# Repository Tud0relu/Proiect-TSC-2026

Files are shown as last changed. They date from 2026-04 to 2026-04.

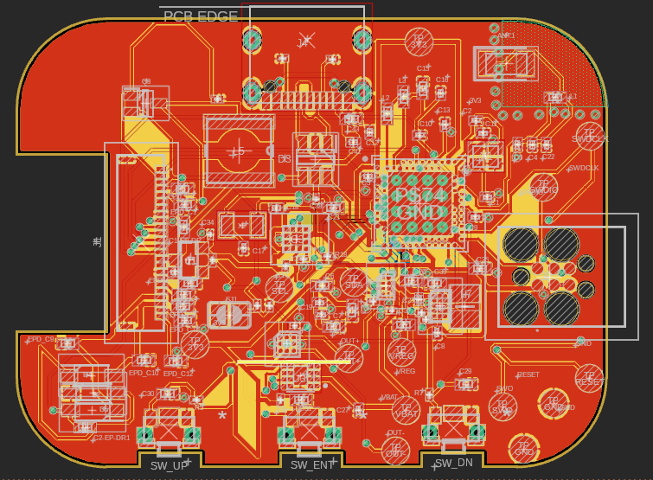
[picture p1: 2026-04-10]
Images/PCB.png

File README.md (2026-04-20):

# InkTime — E-Ink Smartwatch Hardware Documentation

> **InkTime** is a custom smartwatch built around the **Nordic nRF52840** SoC featuring an e-paper (EPD) display, haptic feedback, 3-axis accelerometer, smart battery management, and USB-C charging — all packed into a compact wearable PCB.

---

## Table of Contents

1. [Block Diagram](#block-diagram)
2. [Bill of Materials (BOM)](#bill-of-materials-bom)
3. [Hardware Functionality Description](#hardware-functionality-description)
   - [Microcontroller — Nordic nRF52840](#microcontroller--nordic-nrf52840)
   - [Power Architecture](#power-architecture)
   - [E-Paper Display Interface](#e-paper-display-interface)
   - [IMU — Bosch BMA423](#imu--bosch-bma423)
   - [Haptic Driver — TI DRV2605](#haptic-driver--ti-drv2605)
   - [Fuel Gauge — MAX17048](#fuel-gauge--max17048)
   - [RF & Antenna](#rf--antenna)
   - [User Interface — Buttons](#user-interface--buttons)
   - [USB-C Connectivity](#usb-c-connectivity)
   - [Debug Interface](#debug-interface)
4. [nRF52840 Pin Assignment](#nrf52840-pin-assignment)
5. [Power Consumption Estimates](#power-consumption-estimates)
6. [PCB Design Notes](#pcb-design-notes)
7. [Enclosure](#enclosure)

---

## Block Diagram

```
                        ┌─────────────────────────────────────────────────────┐
                        │                  InkTime PCB                        │
                        │                                                     │
  USB-C (J4)            │  ┌───────────┐     I²C (SDA/SCL)   ┌───────────┐  │
 ──────────────► VBUS ──┼─►│ BQ25180   │◄───────────────────►│ BMA423    │  │
  KH-TYPE-C-16P         │  │ (Charger) │◄──P0.11 INT         │ (IMU)     │  │
                        │  │  IC1      │                      │  IC3      │  │
                        │  └─────┬─────┘  I²C (SDA/SCL)  ┌──┴─────────┐ │  │
                        │        │ SYS ──────────────────►│ DRV2605    │ │  │
  LiPo Battery          │        │           P0.12 EN     │ (Haptic)   │ │  │
 ──────────────► VBAT ──┼────────┤           OUT+/OUT─►  │   IC2      │ │  │
                        │        ▼                       └────────────┘ │  │
                        │  ┌───────────┐                  ┌────────────┐ │  │
                        │  │ RT6160    │  3V3 Rail        │ MAX17048   │ │  │
                        │  │ Buck-Boost│──────────────────► (FuelGauge)│ │  │
                        │  │  IC9      │                  │   U3       │ │  │
                        │  └───────────┘                  └────────────┘ │  │
                        │        │                              I²C ──────┘  │
                        │        │ 3V3                                        │
                        │        ▼                                            │
                        │  ┌─────────────────────────────────────────────┐   │
                        │  │         Nordic nRF52840  (U1)               │   │
                        │  │  BT5.0 + 802.15.4 + ARM Cortex-M4F 64MHz   │   │
                        │  │                                             │   │
                        │  │  SPI ──────────────────────► EPD Display   │   │
                        │  │  I²C ──────────────────────► BMA423 / DRV  │   │
                        │  │  I²C ──────────────────────► MAX17048 / DRV│   │
                        │  │  GPIO ─────────────────────► EPD DC/RST/CS │   │
                        │  │  GPIO ─────────────────────► HAPTIC EN     │   │
                        │  │  GPIO ─────────────────────► Buttons x3    │   │
                        │  │  SWDIO/SWDCLK ─────────────► TC2030 J2     │   │
                        │  │  ANT ──────────────────────► 2450AT18B100E │   │
                        │  └─────────────────────────────────────────────┘   │
                        │                                                     │
                        │  EPD Power Rail (3V3_EPD)  Q1(P-MOSFET) + Q3(N-MOSFET) │
                        │  FPC Connector J1 ──────────────────────► E-Paper Display│
                        └─────────────────────────────────────────────────────┘
```

> **Key interfaces:** SPI (EPD display), I²C (BMA423 + DRV2605 + MAX17048 + BQ25180), USB-C (charging + USB 2.0 FS), SWD (debug/programming).

---

## Bill of Materials (BOM)

| # | Qty | Designator | Component | Value / MPN | Package | JLCPCB / LCSC | Datasheet |
|---|-----|---|---|---|---|---|---|
| 1 | 1 | U1 | Nordic nRF52840 | NRF52840_QF | AQFN-73 7×7mm | — | [Datasheet](https://infocenter.nordicsemi.com/pdf/nRF52840_PS_v1.7.pdf) |
| 2 | 1 | IC1 | Li-Ion charger | BQ25180YBGR | 8-DSBGA 1.6×1.1mm | [C2678081](https://jlcpcb.com/partdetail/TexasInstruments-BQ25180YBGR/C2678081) | [Datasheet](https://www.ti.com/lit/ds/symlink/bq25180.pdf) |
| 3 | 1 | IC2 | Haptic driver ERM/LRA | DRV2605YZFR | 9-BGA 1.44×1.44mm | [C2903721](https://jlcpcb.com/partdetail/TexasInstruments-DRV2605YZFR/C2903721) | [Datasheet](https://www.ti.com/lit/ds/symlink/drv2605.pdf) |
| 4 | 1 | IC3 | Accelerometer | BMA423 | LGA-12 2×2mm | [C332461](https://jlcpcb.com/partdetail/BoschSensortec-BMA423/C332461) | [Datasheet](https://www.bosch-sensortec.com/media/boschsensortec/downloads/datasheets/bst-bma423-ds000.pdf) |
| 5 | 1 | IC9 | Buck-boost DC/DC | RT6160AWSC | WCSP-15 1.4×2.3mm | [C2844520](https://jlcpcb.com/partdetail/Richtek-RT6160AWSC/C2844520) | [Datasheet](https://www.richtek.com/assets/product_file/RT6160A/DS6160A-00.pdf) |
| 6 | 1 | U3 | 1-cell fuel gauge | MAX17048G+T10 | TDFN-8 2×2mm | — | [Datasheet](https://datasheets.maximintegrated.com/en/ds/MAX17048-MAX17049.pdf) |
| 7 | 1 | ANT1 | 2.45 GHz chip antenna | 2450AT18B100E | 3.2×1.6×1.4mm SMD | [C404959](https://jlcpcb.com/partdetail/JohansonDielectrics-2450AT18B100E/C404959) | [Datasheet](https://www.johansontechnology.com/datasheets/2450AT18B100E.pdf) |
| 8 | 1 | J1 | FPC connector 24-pin | 503480-2400 | FPC 0.5mm RA SMD | [C311220](https://jlcpcb.com/partdetail/Molex-503480_2400/C311220) | [Datasheet](https://www.molex.com/pdm_docs/sd/5034802400_sd.pdf) |
| 9 | 1 | J4 | USB Type-C 16-pin | KH-TYPE-C-16P | SMD receptacle | — | [Datasheet](https://www.kinghelm.net/product/kh-type-c-16p.html) |
| 10 | 1 | J2 | SWD debug header | TC2030-IDC | Tag-Connect | — | [Datasheet](https://www.tag-connect.com/wp-content/uploads/bsk-pdf-manager/TC2030-IDC_1.pdf) |
| 11 | 1 | Q1 | P-MOSFET EPD power switch | DMG2305UX-7 | SOT-23 | — | [Datasheet](https://www.diodes.com/assets/Datasheets/DMG2305UX.pdf) |
| 12 | 1 | Q3 | N-MOSFET EPD gate driver | SI1308EDL-T1-GE3 | SC-70 | [C240327](https://jlcpcb.com/partdetail/VishayS-SI1308EDL_T1_GE3/C240327) | [Datasheet](https://www.vishay.com/docs/63399/si1308edl.pdf) |
| 13 | 3 | D2, D4, D5 | Schottky diode 30V/0.5A | MBR0530 | SOD-123 | [C191023](https://jlcpcb.com/partdetail/OnSemiconductor-MBR0530/C191023) | [Datasheet](https://www.onsemi.com/pdf/datasheet/mbr0530-d.pdf) |
| 14 | 1 | D3 | USB 2.0 ESD protection | USBLC6-2SC6Y | SOT-363 | [C145414](https://jlcpcb.com/partdetail/STMicroelectronics-USBLC6_2SC6Y/C145414) | [Datasheet](https://www.st.com/resource/en/datasheet/usblc6-2.pdf) |
| 15 | 1 | L5 | Power inductor 68uH | Würth 744043680 | IND 4.8×2.8mm | [C516667](https://jlcpcb.com/partdetail/WurthElektronik-744043680/C516667) | [Datasheet](https://www.we-online.com/catalog/datasheet/744043680.pdf) |
| 16 | 1 | L7 | Power inductor 0.47uH | FTC252012SR47MBCA | L1608 2×1.6mm | [C5832368](https://jlcpcb.com/partdetail/6763488-FTC252012SR47MBCA/C5832368) | [Datasheet](https://product.tdk.com/info/en/documents/catalog/clq_prog_en_ds_1.pdf) |
| 17 | 1 | X1 | Crystal 32 MHz | 32MHz SMD | Crystal_2016 | — | Nordic reference crystal |
| 18 | 1 | X2 | Crystal 32.768 kHz | 32.768kHz | Crystal_3215 | — | Nordic reference crystal |
| 19 | 3 | SW_UP, SW_DN, SW_ENT | Tactile switch | EVP-AKE31A | SMD | [C2689689](https://jlcpcb.com/partdetail/Panasonic-EVP_AKE31A/C2689689) | [Datasheet](https://industrial.panasonic.com/ww/products/pt/tactile-switches/models/EVP-AKE31A) |
| 20 | 1 | L1 | RF inductor 3.9nH | 3.9nH | 0402 | — | Matching network |
| 21 | 1 | L2 | RF choke 10uH | 10uH | 0402 | — | DC feed |
| 22 | 1 | L3 | RF filter | 15nH | 0402 | — | Matching network |
| 23 | 4 | C14, C20, C21, C6 | MLCC capacitor 4.7uF | 4.7uF | 0402 | — | Decoupling |
| 24 | 7 | C10, C12, C13, C19, C5, C7, C8 | MLCC capacitor 100nF | 100nF | 0201 | — | Decoupling |
| 25 | 3 | C29, C30, C31 | MLCC capacitor 1uF | 1uF | 0402 | — | Button debounce |
| 26 | 3 | C1-EP-DR, C24, C39 | MLCC capacitor 10uF | 10uF | 0402 | — | Bulk decoupling |
| 27 | 9 | EPD_C1..C12 | MLCC capacitor 1uF/50V | 1uF/50V | 0402 | — | EPD power |
| 28 | 2 | R17, R18 | Resistor 3.3kΩ | 3K3 | 0201 | — | I²C pull-up |
| 29 | 2 | R1_USB, R2_USB | Resistor 5.1kΩ | 5K1 | 0201 | — | USB-C CC detection |
| 30 | 3 | R2, R3, R4 | Resistor 7.68kΩ | 7.68k | 0201 | — | Config resistors |
| 31 | 3 | R5, R7, R8 | Resistor 10kΩ | 10k | 0201 | — | Button pull-up |
| 32 | 3 | R2_EP_DR, R9, R_PWR_EPD | Resistor 10kΩ | 10K | 0201 | — | EPD / PMIC bias |
| 33 | 1 | SJ1 | Solder jumper | — | Solder Jumper | — | Config bridge |
| 34 | 14 | TP1–TP6, TP_* | Test points | — | TP_20R | — | Debug/test |

---

## Hardware Functionality Description

### Microcontroller — Nordic nRF52840

The **nRF52840** (U1) is the heart of InkTime. It is a single-chip multiprotocol SoC combining:

- **ARM Cortex-M4F** core @ 64 MHz with FPU
- **1 MB Flash** + **256 KB RAM**
- **Bluetooth 5.0 LE** (1 Mbps/2 Mbps/500 kbps/125 kbps) + IEEE 802.15.4 (Zigbee/Thread)
- **USB 2.0 Full-Speed** device controller (12 Mbps)
- Hardware AES-128 encryption, ARM TrustZone CryptoCell-310
- 48 GPIO pins, 3× TWI (I²C), 4× SPI, 2× UART, 12-bit ADC

The nRF52840 uses the internal DC/DC converter for lower power consumption. Supply is 3.3 V from IC9. Two crystals are used:
- **X1** — 32 MHz (RF clock, high-frequency crystal)
- **X2** — 32.768 kHz (LFCLK for RTC, sleep timekeeping)

The built-in USB 2.0 controller connects directly to the KH-TYPE-C-16P receptacle (J4) via the ESD-protected D+/D− lines, enabling USB DFU firmware updates without a dedicated USB-UART chip.

---

### Power Architecture

```
USB-C (VBUS 5V)
      │
      ▼
  BQ25180YBGR (IC1) ◄── LiPo battery (VBAT)
  Linear charger, up to 1A charge current
      │
      ▼ SYS rail (≈ VBAT or 4.2V when charging)
      │
      ▼
  RT6160AWSC (IC9)
  I²C-programmable buck-boost converter
  Input: 2.5V – 5.5V  |  Output: 3.3V @ up to 800mA
      │
      ▼ 3V3 rail (powers nRF52840, BMA423, DRV2605, MAX17048)
```

**BQ25180YBGR (IC1) — Li-Ion Battery Charger:**
- Input voltage: 3.8V–5.5V (VBUS from USB-C)
- Charge current: configurable via I²C (default ~200 mA, up to 1A)
- Integrated power path management: device runs from VBUS while simultaneously charging
- Interrupt line (!INT) → P0.11: alerts the MCU to status changes (charge complete, fault, OVP)
- I²C address: 0x6B on shared SDA/SCL bus (P0.06/P0.07)

**RT6160AWSC (IC9) — Buck-Boost Regulator:**
- Input: SYS rail (2.6V–5.5V)
- Output: fixed 3.3V ±2% at up to 800mA
- Operates in both step-up (battery near discharge) and step-down (charging) modes
- Enables reliable 3.3V operation down to VBAT ≈ 2.5V, extending battery life
- Enable controlled by VREG signal (always-on in normal operation)
- L7 (0.47uH) is the switching inductor; C25, C33 (22uF) are output caps

**MAX17048G+T10 (U3) — Battery Fuel Gauge:**
- ModelGauge algorithm: estimates State of Charge (SoC %) without coulomb counting
- I²C address: 0x36 on shared I²C bus
- ALERT pin → P0.10 (NFC2): configurable SoC threshold interrupt (e.g., alert at <5%)
- Powered from VBAT directly for always-on monitoring
- Current consumption: 3µA typical in active, 0.5µA in hibernate

---

### E-Paper Display Interface

The watch uses an e-paper (EPD) display connected via **Molex 503480-2400 FPC connector (J1)** — a 24-pin, 0.5mm pitch ZIF socket. The nRF52840 drives the EPD over **SPI** with additional GPIO control lines:

| Signal | nRF52840 Pin | Direction | Function |
|---|---|---|---|
| SCK | P0.02 | OUT | SPI clock |
| MOSI | P0.03 | OUT | SPI data |
| EPD_CS | P0.05 | OUT | Chip select (active low) |
| EPD_DC | P0.15 | OUT | Data/Command select |
| EPD_RST | P0.16 | OUT | Hardware reset (active low) |
| EPD_BUSY | P0.17 | IN | Busy signal from display controller |

**EPD Power Supply:**
The e-paper panel requires a higher-voltage supply (typically 20–40V internally generated by its own controller IC), but its logic/interface side runs on 3.3V. A dedicated **3V3_EPD** rail is created by an additional path controlled by:
- **Q1 (DMG2305UX-7)** — P-channel MOSFET acting as a high-side power switch for the EPD 3.3V supply, controlled by `R_PWR_EPD`
- **Q3 (SI1308EDL)** — N-channel MOSFET for EPD gate driver control
- **D2, D4, D5 (MBR0530)** — Schottky diodes for EPD voltage rail protection and PREVGH/PREVGL rail generation (required by most EPD controllers like UC8176/SSD1680)

This architecture ensures the EPD power is only active when needed, saving power during sleep.

---

### IMU — Bosch BMA423

The **BMA423** (IC3) is a triaxial, low-g accelerometer designed for wearables:

- **Range:** ±2g / ±4g / ±8g / ±16g (configurable)
- **Resolution:** 12-bit
- **Interface:** I²C (address 0x18, CSB pin pulled to VDD → secondary address disabled)
- **Features:** Built-in step counter, wrist-wear wake-up, double-tap/single-tap detection, activity recognition
- **Power:** 170µA active, 2µA in suspend, ~0.9µA in deep suspend
- **Supply:** 1.71V–3.6V (VDDIO and VDD both connected to 3.3V rail)

**Connections:**
- SDA → P0.06 (shared I²C bus)
- SCL → P0.07 (shared I²C bus)
- INT1 → P0.08: wake-up interrupt (step counter, gesture)
- INT2 → P1.08: secondary interrupt (configurable)
- CSB → 3V3 (I²C mode selection)

The BMA423 enables the watch to detect wrist rotation (raise-to-wake), count steps, and recognize sleep/wake cycles without MCU involvement.

---

### Haptic Driver — TI DRV2605

The **DRV2605YZFR** (IC2) provides haptic feedback to a motor (ERM or LRA type):

- **Interface:** I²C (address 0x5A)
- **Built-in waveform library:** 123 pre-loaded haptic waveforms (ROM)
- **Smart Loop Architecture:** auto-resonance tracking for LRA motors
- **Overdrive/brake control** for precise tactile feel
- **Supply:** 2.7V–5.5V (connected to local 3.3V rail)
- **Output current:** ±1.2A peak

**Connections:**
- SDA → P0.06 (shared I²C bus)
- SCL → P0.07 (shared I²C bus)
- EN → P0.12: enable pin (active high, controls driver power state)
- OUT+ / OUT− → motor terminals (differential drive)
- REG output decoupled by C32 (1uF)

I²C address 0x5A is hardwired (ADDR pin tied to GND internally).

---

### RF & Antenna

The **2450AT18B100E** (ANT1) from Johanson Technology is a multilayer ceramic chip antenna tuned for 2.4–2.5 GHz:

- **Gain:** 0 dBi typical
- **Impedance:** 50Ω
- **Size:** 3.2×1.6×1.4mm

RF matching network (π-filter):
- **L1** (3.9nH) — series matching inductor from ANT pin of nRF52840
- **C3, C4** (1pF each) — shunt capacitors for impedance matching
- **L2** (10uH) + **DCC** node — DC feed inductor for the internal PA supply
- **C9** (820pF), **C11** (100pF), **C3/C4** (1pF) — harmonics filtering

The antenna is placed at the corner of the PCB, away from the battery, with a keep-out zone under the radiating element per Nordic reference design guidelines.

---

### User Interface — Buttons

Three tactile switches (**Panasonic EVP-AKE31A**) provide the user interface:

| Designator | Function | nRF52840 Pin | Pull-up | Debounce Cap |
|---|---|---|---|---|
| SW_UP | Scroll Up / Confirm | P0.13 | R5 (10kΩ) | C30 (1uF) |
| SW_ENT | Enter / Select | P0.14 | R8 (10kΩ) | C31 (1uF) |
| SW_DN | Scroll Down / Back | P1.02 | R7 (10kΩ) | C29 (1uF) |

All buttons are **active-low** — pressing connects the GPIO to GND through the switch. The pull-up resistors (10kΩ) are tied to the 3.3V rail. Hardware RC debouncing is achieved by the 1uF capacitors in parallel with the switches.

The nRF52840 GPIOTE module handles button interrupts with minimal power overhead.

---

### USB-C Connectivity

The **KH-TYPE-C-16P** (J4) is a 16-pin USB Type-C receptacle providing:

- **VBUS (5V)** → IC1 (BQ25180) for charging
- **D+ / D−** → nRF52840 P0.12/P0.13 equivalent USB data pins for USB 2.0 FS
- **CC1 / CC2** → R1_USB, R2_USB (5.1kΩ each to GND): configure the port as a UFP (power sink), telling the attached charger to provide 5V/standard current
- **USBLC6-2SC6Y (D3)** — bidirectional TVS diode array on D+/D− lines for IEC 61000-4-2 ESD protection (±8kV contact discharge)

The nRF52840's built-in USB Full-Speed device controller (12 Mbps) enables:
- USB DFU (Device Firmware Upgrade) — drag-and-drop firmware flashing
- USB CDC (virtual serial port) — debug logging
- USB HID — optional time sync interface

---

### Debug Interface

**Tag-Connect TC2030-IDC (J2)** is a 6-pin spring-loaded programming/debug connector with no PCB footprint pins, saving board space:

| Pin | Signal | Function |
|-----|---|---|
| 1 | 3V3 | Target power sense |
| 2 | SWDIO | Serial Wire Debug I/O |
| 3 | GND | Ground |
| 4 | SWDCLK | Serial Wire Debug Clock |
| 5 | GND | Ground |
| 6 | RESET | nRF52840 hardware reset |

Additional debug test points on PCB: `TP_SWDIO`, `TP_SWDCLK`, `TP_3V3`, `TP_VBAT`, `TP_VREG`, `TP_SDA`, `TP_SCL`, `TP_ON`, `TP_OP`, `TP_SWO` (Serial Wire Output for ITM tracing).

---

## nRF52840 Pin Assignment

| GPIO Pin | Net / Signal | Connected To | Function |
|---|---|---|---|
| P0.00 / XL1 | P0.00/XL1 | X2 pin 1, C17 | 32.768 kHz LFXO in |
| P0.01 / XL2 | P0.01/XL2 | X2 pin 2, C18 | 32.768 kHz LFXO out |
| P0.02 / AIN0 | SCK | EPD FPC (J1 via schematic) | SPI clock for e-paper |
| P0.03 / AIN1 | MOSI | EPD FPC (J1) | SPI MOSI for e-paper |
| P0.05 / AIN3 | EPD_CS | EPD FPC (J1) | EPD chip select (active low) |
| P0.06 | SDA | IC1, IC3, IC2, U3, R2, R18 | I²C data (shared bus) |
| P0.07 | SCL | IC1, IC3, IC2, U3, R4, R17 | I²C clock (shared bus) |
| P0.08 | IMU_INT1 | IC3 (BMA423) INT1 | IMU interrupt 1 (step / wake) |
| P0.10 / NFC2 | ALERT | U3 (MAX17048) ALERT | Fuel gauge low-battery alert |
| P0.11 | PMIC_INT | IC1 (BQ25180) !INT | Charger status interrupt |
| P0.12 | HAPTIC_EN | IC2 (DRV2605) EN | Haptic driver enable |
| P0.13 | P0.13 | SW_UP, R5, C30 | Button UP (active low) |
| P0.14 | P0.14 | SW_ENT, R8, C31 | Button ENTER (active low) |
| P0.15 | EPD_DC | EPD FPC (J1) | EPD data/command select |
| P0.16 | EPD_RST | EPD FPC (J1) | EPD reset (active low) |
| P0.17 | EPD_BUSY | EPD FPC (J1) | EPD busy status input |
| P0.18 / RESET | RESET | J2 pin 6, TP_RESET | Hardware reset (active low) |
| P1.00 | SWO | TP_SWO | Serial Wire Output (ITM trace) |
| P1.02 | P1.02 | SW_DN, R7, C29 | Button DOWN (active low) |
| P1.08 | IMU_INT2 | IC3 (BMA423) INT2 | IMU interrupt 2 (configurable) |
| SWDIO | SWDIO | J2 pin 2, TP_SWDIO | SWD debug data |
| SWDCLK | SWDCLK | J2 pin 4, TP_SWDCLK | SWD debug clock |
| VBUS | VBUS | IC1 IN, C38, C21 | USB VBUS sense |
| D+ | D+ | J4, D3 | USB 2.0 FS D+ |
| D− | D− | J4, D3 | USB 2.0 FS D− |
| XC1/XC2 | N$3/N$4 | X1, C1, C2 | 32 MHz HFXO crystal |
| ANT | N$7 | L1, C3 | RF antenna feed |
| DCC | N$9 | L2 | PA DC feed |
| VDD (×4) | 3V3 | C6, C7, C8, C14 + IC9 VOUT | 3.3V supply |
| VDDH | 3V3 | IC9 VOUT | High-drive GPIO supply |
| VSS / VSS_PA / VSS_PAD | GND | Ground pour | Ground |

**I²C Bus Summary (P0.06 SDA / P0.07 SCL, 400 kHz Fast Mode):**

| Device | I²C Address | Pull-up |
|---|---|---|
| BQ25180 (IC1) | 0x6B | R2, R18 (3.3kΩ each) |
| BMA423 (IC3) | 0x18 | R2, R18 (3.3kΩ each) |
| DRV2605 (IC2) | 0x5A | R2, R18 (3.3kΩ each) |
| MAX17048 (U3) | 0x36 | R2, R18 (3.3kΩ each) |

All four devices share a single I²C bus with 3.3kΩ pull-up resistors (R17, R18 to 3V3). Effective pull-up for fast-mode at 400 kHz with 4 devices at ~100pF bus capacitance is within spec.

---

## Power Consumption Estimates

| State | Subsystem Active | Current Draw | Notes |
|---|---|---|---|
| **Deep sleep** | nRF52840 System OFF, RTC running | ~5–10 µA | 32.768kHz RTC, BMA wake-on-tilt |
| **BLE advertising** | nRF52840 BLE adv @ 1s interval | ~60–80 µA avg | Connectable undirected advertising |
| **BLE connected** | Connection interval 50ms | ~200–400 µA avg | — |
| **EPD update** | nRF52840 + EPD refresh 2s | ~15–25 mA peak | EPD full refresh draws spike current |
| **Haptic pulse** | DRV2605 + LRA 200ms | ~50–150 mA peak | Short pulses only |
| **Charging @ 200mA** | BQ25180 charging | 200 mA from VBUS | CC/CV profile |

**Estimated average daily consumption** (light wrist-watch use):
- 22h deep sleep (5µA) + 1h BLE connected (300µA) + 48 EPD updates/day (avg 0.5mA ×2s) ≈ **~0.4–0.6 mAh/day**

With a **100 mAh LiPo**, estimated battery life: **>6 months** with e-ink always-on display and minimal Bluetooth. With active BLE and hourly notifications, expect **4–8 weeks**.

---

## PCB Design Notes

- **Layer stack:** 2-layer PCB (Top + Bottom copper), 1.0mm FR4
- **Board dimensions:** ~45mm × 38mm (designed to fit circular wristwatch case)
- **Minimum trace width:** 0.1mm signal, 0.3mm power
- **Minimum clearance:** 0.1mm
- **Minimum drill:** 0.2mm (vias), 0.3mm annular ring
- **Surface finish:** HASL or ENIG (ENIG recommended for BGA/LGA pads)
- **Solder mask:** Green (standard), openings on all SMD pads
- **Component side:** All components on Top layer (single-sided SMT assembly possible)
- **Antenna keep-out:** 5mm clearance under 2450AT18B100E antenna element
- **Decoupling strategy:** 100nF 0201 caps placed within 0.5mm of each VDD pin, 4.7uF 0402 bulk caps placed per power domain

**Design Rules (JLCPCB 2-layer standard):**
- Min trace/space: 5/5 mil
- Min hole: 0.3mm
- Board outline tolerance: ±0.2mm
- Copper to board edge: ≥0.3mm

---

## Enclosure

The InkTime watch case is designed in **Autodesk Fusion 360** to fit the PCB precisely. Key features:

- **Outer dimensions:** 46mm × 38mm × 12mm (approximately)
- **Display window:** cutout for the EPD panel, with recessed bezel for protection
- **USB-C port cutout:** access to J4 on the bottom edge
- **Button apertures:** 3 side-mounted holes aligned with SW_UP, SW_ENT, SW_DN
- **Strap lugs:** 20mm standard watch band attachment points
- **PCB mounting:** 4× M1.4 screw bosses aligned with PCB corner keepout zones
- **Battery compartment:** cavity on back for 380mAh/100mAh flat LiPo cell
- **Material:** PLA/PETG for prototyping; Aluminum CNC or SLA resin for production

The 3D model is provided as `3DmodelFull.f3z` (Fusion 360 archive) and `3D.step` (neutral STEP format for other CAD tools).

---

## Repository Structure

```
Proiect-TSC-2026/
│
├── Hardware/
│   ├── PCB.brd
│   └── Schematic.sch
│
├── Images/
│   └── PCB.png
│
├── Manufactoring/
│   ├── PCB.cpl
│   ├── Schematic.bom.txt
│   └── gerber.zip
│
├── Mechanical/
│   ├── 3D.step
│   └── PCB_3D.f3d
│
├── LICENSE
└── README.md
```

---

*Project: InkTime Smartwatch | Hardware revision 6 | April 2026*

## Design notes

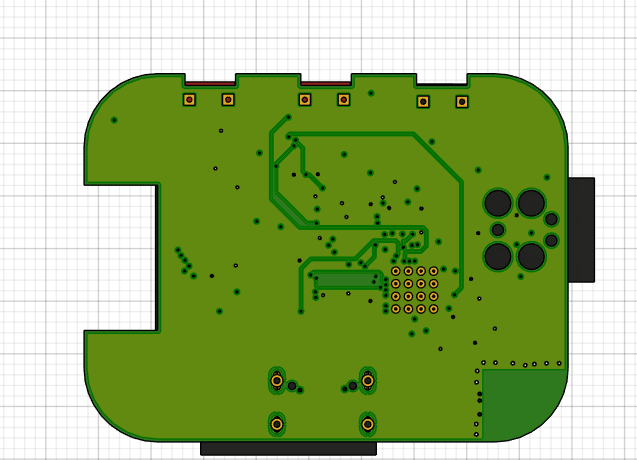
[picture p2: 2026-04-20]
Images/Screenshot 2026-04-20 180116.png

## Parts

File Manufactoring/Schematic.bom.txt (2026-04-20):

Partlist exported from C:/Users/TUDOR/AppData/Local/Temp/Neutron/ElectronFileOutput/13904/sch-776d997c-0de5-4aaf-b012-ae330e367f24/Schematic.sch at 4/20/2026 2:44 PM

Part        Value                                                   Device                                                                       Footprint Name                                                                                                         Detailed Description                                                                                                      ARROW_PART_NUMBER ARROW_PRICE-STOCK                                                                                AVAILABILITY CHECK_PRICES                                                                       COPYRIGHT                                                DESCRIPTION                                                                                                    DIGI-KEY_PART_NUMBER_1 DIGI-KEY_PART_NUMBER_2 DIGI-KEY_PART_NUMBER_3 HEIGHT  JLCPCB                                                           MANUFACTURER_NAME   MANUFACTURER_PART_NUMBER MF                 MFR_NAME          MOUSER_PART_NUMBER MOUSER_PRICE-STOCK                                                                                           MP               PACKAGE                      POPULARITY PRICE PROD_ID    PURCHASE-URL                                                                                                                                    SNAPEDA_LINK                                                                        TP_SIGNAL_NAME VALUE             
ANT1        2450AT18B100E                                           2450AT18B100E_2450AT18B100E                                                  2450AT18B100E_ANTC3216X140N                                                                                            Antennas 2.45GHz ANTENNA                                                                                                  2450AT18B100E     https://www.arrow.com/en/products/2450at18b100e/johanson-dielectrics?utm_currency=USD&region=nac                                                                                                                                                          Antennas 2.45GHz ANTENNA                                                                                                                                                            1.4mm                                                                    JOHANSON TECHNOLOGY 2450AT18B100E                                                 609-2450AT18B100E  https://www.mouser.co.uk/ProductDetail/Johanson-Technology/2450AT18B100E?qs=yCnrNFeXz%252Bh5MFsFIXGZGA%3D%3D                                                                                                                                                                                                                                                                                                                                                
C1          12pF                                                    NORDIC_NRF_3_CAPACITOR_0201_L                                                NORDIC_NRF_3_RESC0201_L                                                                                                Generic chip capacitor                                                                                                                                                                                                                                                                                                                                                                                                                                                                                                                                                                                                                                                                                                                                                                                                                                                                                                                                                                                                                                                                                                                                                                                                              
C1-EP-DR    10uF                                                    PERFECT_0402_CAP_0402                                                        PERFECT_0402_0402                                                                                                      0402 (1005 Metric)                                                                                                                                                                                                                                                                                                                                                                                                                                                                                                                                                                                                                                                                                                                                                                                                                                                                                                                                                                                                                                                                                                                                                                                                                  
C2          12pF                                                    NORDIC_NRF_3_CAPACITOR_0201_L                                                NORDIC_NRF_3_RESC0201_L                                                                                                Generic chip capacitor                                                                                                                                                                                                                                                                                                                                                                                                                                                                                                                                                                                                                                                                                                                                                                                                                                                                                                                                                                                                                                                                                                                                                                                                              
C2-EP-DR1   4.7uF/25V                                               PERFECT_0402_CAP_0402                                                        PERFECT_0402_0402                                                                                                      0402 (1005 Metric)                                                                                                                                                                                                                                                                                                                                                                                                                                                                                                                                                                                                                                                                                                                                                                                                                                                                                                                                                                                                                                                                                                                                                                                                                  
C3          1pF                                                     NORDIC_NRF_3_CAPACITOR_0201_L                                                NORDIC_NRF_3_RESC0201_L                                                                                                Generic chip capacitor                                                                                                                                                                                                                                                                                                                                                                                                                                                                                                                                                                                                                                                                                                                                                                                                                                                                                                                                                                                                                                                                                                                                                                                                              
C4          1pF                                                     NORDIC_NRF_3_CAPACITOR_0201_L                                                NORDIC_NRF_3_RESC0201_L                                                                                                Generic chip capacitor                                                                                                                                                                                                                                                                                                                                                                                                                                                                                                                                                                                                                                                                                                                                                                                                                                                                                                                                                                                                                                                                                                                                                                                                              
C5          100nF                                                   NORDIC_NRF_3_CAPACITOR_0201_L                                                NORDIC_NRF_3_RESC0201_L                                                                                                Generic chip capacitor                                                                                                                                                                                                                                                                                                                                                                                                                                                                                                                                                                                                                                                                                                                                                                                                                                                                                                                                                                                                                                                                                                                                                                                                              
C6          4.7µF                                                   PERFECT_0402_CAP_0402                                                        PERFECT_0402_0402                                                                                                      0402 (1005 Metric)                                                                                                                                                                                                                                                                                                                                                                                                                                                                                                                                                                                                                                                                                                                                                                                                                                                                                                                                                                                                                                                                                                                                                                                                                  
C7          100nF                                                   NORDIC_NRF_3_CAPACITOR_0201_L                                                NORDIC_NRF_3_RESC0201_L                                                                                                Generic chip capacitor                                                                                                                                                                                                                                                                                                                                                                                                                                                                                                                                                                                                                                                                                                                                                                                                                                                                                                                                                                                                                                                                                                                                                                                                              
C8          100nF                                                   NORDIC_NRF_3_CAPACITOR_0201_L                                                NORDIC_NRF_3_RESC0201_L                                                                                                Generic chip capacitor                                                                                                                                                                                                                                                                                                                                                                                                                                                                                                                                                                                                                                                                                                                                                                                                                                                                                                                                                                                                                                                                                                                                                                                                              
C9          820pF N.C.                                              NORDIC_NRF_3_CAPACITOR_0201_L                                                NORDIC_NRF_3_RESC0201_L                                                                                                Generic chip capacitor                                                                                                                                                                                                                                                                                                                                                                                                                                                                                                                                                                                                                                                                                                                                                                                                                                                                                                                                                                                                                                                                                                                                                                                                              
C10         N.C.                                                    PERFECT_0402_CAP_0402                                                        PERFECT_0402_0402                                                                                                      0402 (1005 Metric)                                                                                                                                                                                                                                                                                                                                                                                                                                                                                                                                                                                                                                                                                                                                                                                                                                                                                                                                                                                                                                                                                                                                                                                                                  
C11         100pF                                                   NORDIC_NRF_3_CAPACITOR_0201_L                                                NORDIC_NRF_3_RESC0201_L                                                                                                Generic chip capacitor                                                                                                                                                                                                                                                                                                                                                                                                                                                                                                                                                                                                                                                                                                                                                                                                                                                                                                                                                                                                                                                                                                                                                                                                              
C12         100nF                                                   NORDIC_NRF_3_CAPACITOR_0201_L                                                NORDIC_NRF_3_RESC0201_L                                                                                                Generic chip capacitor                                                                                                                                                                                                                                                                                                                                                                                                                                                                                                                                                                                                                                                                                                                                                                                                                                                                                                                                                                                                                                                                                                                                                                                                              
C13         N.C.                                                    PERFECT_0402_CAP_0402                                                        PERFECT_0402_0402                                                                                                      0402 (1005 Metric)                                                                                                                                                                                                                                                                                                                                                                                                                                                                                                                                                                                                                                                                                                                                                                                                                                                                                                                                                                                                                                                                                                                                                                                                                  
C14         4.7µF                                                   PERFECT_0402_CAP_0402                                                        PERFECT_0402_0402                                                                                                      0402 (1005 Metric)                                                                                                                                                                                                                                                                                                                                                                                                                                                                                                                                                                                                                                                                                                                                                                                                                                                                                                                                                                                                                                                                                                                                                                                                                  
C15         1.0µF                                                   PERFECT_0402_CAP_0402                                                        PERFECT_0402_0402                                                                                                      0402 (1005 Metric)                                                                                                                                                                                                                                                                                                                                                                                                                                                                                                                                                                                                                                                                                                                                                                                                                                                                                                                                                                                                                                                                                                                                                                                                                  
C16         47nF                                                    NORDIC_NRF_3_CAPACITOR_0201_L                                                NORDIC_NRF_3_RESC0201_L                                                                                                Generic chip capacitor
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

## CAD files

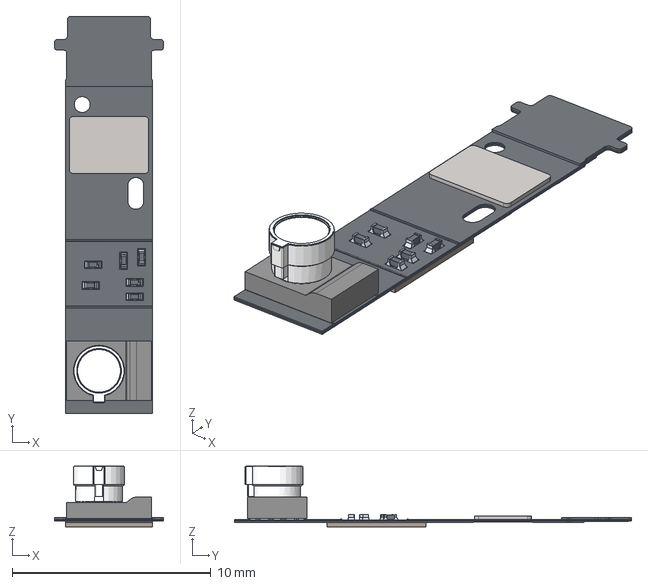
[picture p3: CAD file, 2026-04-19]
Mechanical/3D.step
5.50 x 20.0 x 3.07 mm

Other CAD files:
Mechanical/PCB_3D.f3d

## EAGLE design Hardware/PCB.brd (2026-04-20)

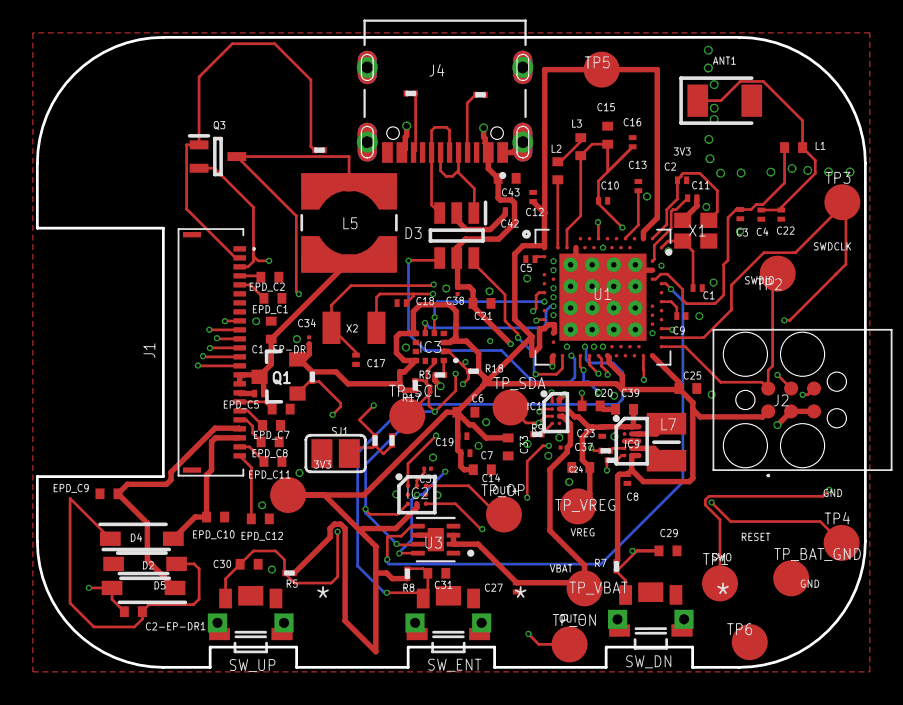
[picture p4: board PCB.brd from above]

Board: 4 copper layers, 46.0 x 35.0 mm, 105 parts (0 on the bottom side), 70 nets.

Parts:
ANT1: 2450AT18B100E; 2450AT18B100E_ANTC3216X140N
C1, C2, C17, C18: 12pF; NORDIC_NRF_3_RESC0201_L
C1-EP-DR, C24, C39: 10uF; NORDIC_NRF_3_RESC0402_L
C2-EP-DR1: 4.7uF/25V; NORDIC_NRF_3_RESC0402_L
C3, C4: 1pF; NORDIC_NRF_3_RESC0201_L
C5, C7, C8, C12, C19: 100nF; NORDIC_NRF_3_RESC0201_L
C6, C14, C20, C21: 4.7µF; NORDIC_NRF_3_RESC0402_L
C9: 820pF; NORDIC_NRF_3_RESC0201_L
C10, C13: NORDIC_NRF_3_RESC0201_L
C11: 100pF; NORDIC_NRF_3_RESC0201_L
C15: 1.0µF; NORDIC_NRF_3_RESC0402_L
C16: 47nF; NORDIC_NRF_3_RESC0201_L
C22: N.C.; NORDIC_NRF_3_RESC0201_L
C23, C27, C42: 0.1uF; NORDIC_NRF_3_RESC0201_L
C25, C33: 22uF; NORDIC_NRF_3_RESC0402_L
C29, C30, C31: 1uF; NORDIC_NRF_3_RESC0402_L
C32, C37, C38: 1uF; GRM011R60J152KE01L_2_CAPC0201X13N
C34: 0.1uF; GRM011R60J152KE01L_2_CAPC0201X13N
C43: 4.7uF; NORDIC_NRF_3_RESC0402_L
D2, D4, D5: MBR0530; ESP32_C6_LIBRARY_5_SOD3716X135N
D3: USBLC6-2SC6Y; ESP32_C6_LIBRARY_3_SOT95P280X145-6N
EPD_C1, EPD_C2, EPD_C6, EPD_C7, EPD_C8, EPD_C9, EPD_C10, EPD_C11, EPD_C12: 1uF/50V; NORDIC_NRF_3_RESC0402_L
EPD_C5: 0.1uF/50V; NORDIC_NRF_3_RESC0201_L
IC1: BQ25180YBGR; BQ25180YBGR_BGA8C40P2X4_100X155X50
IC2: DRV2605YZFR; DRV2605YZFR_BGA9C50P3X3_144X144X62
IC3: BMA423; BMA423_BMA423
IC9: RT6160AWSC; RT6160AWSC_BGA15C40P3X5_140X230X60
J1: 503480-2400; 503480-2400_5034802400
J2: TC2030-IDC; TC2030-IDC_TC2030IDC
J4: KH-TYPE-C-16P; KH-TYPE-C-16P_KINGHELM_KH-TYPE-C-16P
L1: 3.9nH; NORDIC_NRF_2_RESC0402_L
L2: 10µH; NORDIC_NRF_2_RESC0402_L
L3: 15nF; NORDIC_NRF_2_RESC0402_L
L5: 68uH; ESP32_C6_LIBRARY_2_IND_4828-WE-TPC_WRE
L7: FTC252012SR47MBCA; MLP2016SR47MT0S1_INDC2016X100N
Q1: 20V/4.2A/52mΩ/1.4W; ESP32_C6_LIBRARY_4_ESP32_C6_LIBRARY_4_ESP32_C6_LIBRARY_4_ES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
Q3: SI1308EDL-T1-GE3; ESP32_C6_LIBRARY_6_SOT65P210X110-3N
R1_EP_DR: 0.47; CPF0201D7K68C1_0201
R1_USB, R2_USB: 5K1; ERA-1AEB3401C_0201
R2, R3, R4: CPF0201D7K68C1_CPF0201D7K68C1; CPF0201D7K68C1_0201
R2_EP_DR, R9: 10K; CPF0201D7K68C1_0201
R5, R7, R8: 10k; CPF0201D7K68C1_0201
R17, R18: 3K3; CPF0201D7K68C1_0201
R_PWR_EPD: 10K; CPF0201D7K68C1_0201
R_TYPE_SEL: 2.2; CPF0201D7K68C1_0201
SJ1: ESP32_C6_LIBRARY_7_JUMPER_SJ
SW_DN: 2025-10-22_07-23-44_LIBRARY_EVP-AKE31ASW_EVP-AKE3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; 2025-10-22_07-23-44_LIBRARY_SW_EVP-AKE31A_PAN
SW_ENT: SW_ENT; 2025-10-22_07-23-44_LIBRARY_SW_EVP-AKE31A_PAN
SW_UP: 2025-10-22_07-23-44_LIBRARY_EVP-AKE31ASW_EVP-AKE3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; 2025-10-22_07-23-44_LIBRARY_SW_EVP-AKE31A_PAN
TP1, TP2, TP3, TP4, TP5, TP6: HECTOR_WATCH_1_TPTP20R; HECTOR_WATCH_1_TP20R
TP_3V3: HECTOR_WATCH_1_TPTP20R; HECTOR_WATCH_1_TP20R
TP_BAT_GND: HECTOR_WATCH_1_TPTP20R; HECTOR_WATCH_1_TP20R
TP_ON: HECTOR_WATCH_1_TPTP20R; HECTOR_WATCH_1_TP20R
TP_OP: HECTOR_WATCH_1_TPTP20R; HECTOR_WATCH_1_TP20R
TP_SCL: HECTOR_WATCH_1_TPTP20R; HECTOR_WATCH_1_TP20R
TP_SDA: HECTOR_WATCH_1_TPTP20R; HECTOR_WATCH_1_TP20R
TP_VBAT: HECTOR_WATCH_1_TPTP20R; HECTOR_WATCH_1_TP20R
TP_VREG: HECTOR_WATCH_1_TPTP20R; HECTOR_WATCH_1_TP20R
U1: NRF52840_QF; NORDIC_NRF_4_AQFN50P700X700X85_HS-74N
U3: MAX17048G+T10; ESP32_C6_LIBRARY_SON50P200X200X80-9N
X1: 32MHz; NORDIC_NRF_BT-XTAL_2016_N
X2: 32.768kHz; NORDIC_NRF_1_XTAL_3215_N

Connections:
3V3: C6.1, C7.1, C8.1, C12.1, C14.1, C19.1, C25.1, C33.1, C34.2, IC2.C2, IC3.3, IC3.7, IC3.10, IC9.E2, IC9.E3, J2.1, Q1.2, R5.2, R7.2, R8.2, R17.1, R18.1, R_PWR_EPD.2, TP5.TP, TP_3V3.TP, U1.P$A22, U1.P$AD14, U1.P$AD23, U1.P$B1, U1.P$W1, U1.P$Y2
ALERT: U1.P$J24, U3.5
D+: D3.4, U1.P$AD6
D-: D3.6, U1.P$AD4
DN: D3.1, J4.A7, J4.B7
DP: D3.3, J4.A6, J4.B6
EPD_3V3: C1-EP-DR.1, EPD_C5.2, J1.15, J1.16, L5.2, Q1.3
EPD_BUSY: J1.9, U1.P$AD12
EPD_CS: J1.12, U1.P$K2
EPD_DC: J1.11, U1.P$AD10
EPD_RST: J1.10, U1.P$AC11
GDR: J1.2, Q3.1, R2_EP_DR.2
GND: C1.2, C1-EP-DR.2, C2.2, C3.2, C4.2, C5.2, C6.2, C7.2, C8.2, C9.2, C10.1, C11.2, C12.2, C13.1, C14.2, C15.2, C16.2, C17.1, C18.1, C19.2, C20.2, C21.2, C22.2, C23.1, C24.1, C25.2, C27.2, C29.2, C30.2, C31.2, C32.1, C33.2, C34.1, C37.1, C38.1, C39.2, C42.2, C43.2, D2.1, D3.2, EPD_C1.1, EPD_C2.1, EPD_C5.1, EPD_C6.1, EPD_C7.1, EPD_C8.1, EPD_C9.1, EPD_C10.1, EPD_C11.1, EPD_C12.1, IC1.D2, IC2.B1, IC2.B3, IC3.8, IC3.9, IC9.B1, IC9.C1, IC9.C2, IC9.C3, J1.8, J1.17, J1.MP1, J1.MP2, J2.3, J2.5, J4.A1_B12, J4.A12_B1, J4.SH1, J4.SH2, J4.SH3, J4.SH4, R1_USB.1, R2_EP_DR.1, R2_USB.2, R3.1, R9.1, R_TYPE_SEL.1, SJ1.1, SW_DN.1, SW_ENT.1, SW_UP.1, TP6.TP, TP_BAT_GND.TP, U1.P$74, U1.P$75, U1.P$76, U1.P$77, U1.P$78, U1.P$79, U1.P$80, U1.P$81, U1.P$82, U1.P$83, U1.P$84, U1.P$85, U1.P$86, U1.P$87, U1.P$88, U1.P$89, U1.P$90, U1.P$B7, U1.P$F23, U3.1, U3.4, U3.6, U3.9, X1.2, X1.4
HAPTIC_EN: IC2.A1, U1.P$U1
IMU_INT1: IC3.5, U1.P$N1
IMU_INT2: IC3.6, U1.P$P2
LX1: IC9.B2, IC9.B3, L7.1
LX2: IC9.D2, IC9.D3, L7.2
MOSI: J1.14, U1.P$B13
unnamed: C5.1, U1.P$C1
unnamed: C9.1, U1.P$N24
unnamed: C11.1, U1.P$D23
unnamed: IC9.D1, R4.2
unnamed: C17.2, U1.P$D2, X2.2
unnamed: C18.2, U1.P$F2, X2.1
unnamed: C2-EP-DR1.2, D5.2, L5.1, Q3.3
unnamed: C3.1, L1.1, U1.P$H23
unnamed: ANT1.1, C4.1, C22.1, L1.2
unnamed: C10.2, C15.1, C16.1, L3.1, U1.P$B5, U1.P$E24
unnamed: C2.1, U1.P$A23, X1.3
unnamed: C1.1, U1.P$B24, X1.1
unnamed: L2.1, L3.2
unnamed: L2.2, U1.P$B3
unnamed: C13.2, U1.P$A18
unnamed: IC3.1, R3.2
unnamed: C20.1, U1.P$AC5
unnamed: IC9.E1, R2.2
unnamed: EPD_C8.2, J1.20
unnamed: IC1.D1, R9.2
unnamed: C2-EP-DR1.1, D2.2, D4.1
unnamed: EPD_C2.2, J1.4
unnamed: R1_EP_DR.1, R_TYPE_SEL.2, SJ1.2
unnamed: EPD_C1.2, J1.5
unnamed: C32.2, IC2.A2
unnamed: J4.B5, R2_USB.1
unnamed: J4.A5, R1_USB.2
unnamed: EPD_C7.2, J1.19
unnamed: EPD_C6.2, J1.18
unnamed: EPD_C11.2, J1.23
unnamed: EPD_C12.2, J1.24
OUT+: IC2.A3, TP_OP.TP
OUT-: IC2.C3, TP_ON.TP
P0.13: C30.1, R5.1, SW_UP.2, U1.P$AD8
P0.14: C31.1, R8.1, SW_ENT.2, U1.P$AC9
P1.01: Q1.1, R_PWR_EPD.1, U1.P$Y23
P1.02: C29.1, R7.1, SW_DN.2, U1.P$W24
PMIC_INT: IC1.A1, U1.P$T2
PREVGH: D5.1, EPD_C9.2, J1.21
PREVGL: D4.2, EPD_C10.2, J1.22
RESE: J1.3, Q3.2, R1_EP_DR.2
RESET: J2.6, TP4.TP, U1.P$AC13
SCK: J1.13, U1.P$A12
SCL: IC1.B1, IC2.C1, IC3.12, R4.1, R17.2, TP_SCL.TP, U1.P$M2, U3.7
SDA: IC1.C1, IC2.B2, IC3.2, R2.1, R18.2, TP_SDA.TP, U1.P$L1, U3.8
SWDCLK: J2.4, TP3.TP, U1.P$AA24
SWDIO: J2.2, TP2.TP, U1.P$AC24
SWO: TP1.TP, U1.P$AD22
VBAT: C27.1, C37.2, IC1.C2, TP_VBAT.TP, U3.2, U3.3
VBUS: C21.1, C38.2, C42.1, C43.1, D3.5, IC1.A2, J4.A4_B9, J4.A9_B4, U1.P$AD2
VREG: C23.2, C24.2, C39.1, IC1.B2, IC9.A1, IC9.A2, IC9.A3, TP_VREG.TP

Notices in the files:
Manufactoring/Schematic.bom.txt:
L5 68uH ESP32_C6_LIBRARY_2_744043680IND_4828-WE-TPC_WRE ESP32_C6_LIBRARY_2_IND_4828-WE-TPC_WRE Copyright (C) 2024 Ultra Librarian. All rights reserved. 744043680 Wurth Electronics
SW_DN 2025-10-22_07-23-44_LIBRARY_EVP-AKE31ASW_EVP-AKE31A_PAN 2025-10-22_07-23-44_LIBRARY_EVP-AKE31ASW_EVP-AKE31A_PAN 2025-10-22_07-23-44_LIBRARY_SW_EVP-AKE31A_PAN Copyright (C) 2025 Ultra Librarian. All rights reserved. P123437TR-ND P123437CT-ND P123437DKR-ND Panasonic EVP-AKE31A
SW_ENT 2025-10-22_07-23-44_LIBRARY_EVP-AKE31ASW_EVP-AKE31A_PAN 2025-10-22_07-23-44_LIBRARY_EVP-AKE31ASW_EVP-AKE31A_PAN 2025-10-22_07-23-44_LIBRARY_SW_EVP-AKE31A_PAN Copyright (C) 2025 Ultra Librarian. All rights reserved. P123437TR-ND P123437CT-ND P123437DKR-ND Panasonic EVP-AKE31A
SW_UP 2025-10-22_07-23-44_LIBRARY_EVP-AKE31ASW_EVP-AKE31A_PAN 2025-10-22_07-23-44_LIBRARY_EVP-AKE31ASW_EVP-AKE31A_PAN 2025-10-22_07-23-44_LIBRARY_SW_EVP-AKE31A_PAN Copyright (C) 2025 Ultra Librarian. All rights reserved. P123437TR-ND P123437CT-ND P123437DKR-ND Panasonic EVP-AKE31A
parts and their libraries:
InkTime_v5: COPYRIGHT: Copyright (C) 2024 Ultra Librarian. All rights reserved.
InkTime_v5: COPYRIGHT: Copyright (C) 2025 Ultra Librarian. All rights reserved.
